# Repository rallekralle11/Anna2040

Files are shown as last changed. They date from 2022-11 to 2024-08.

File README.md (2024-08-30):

# Anna 2040

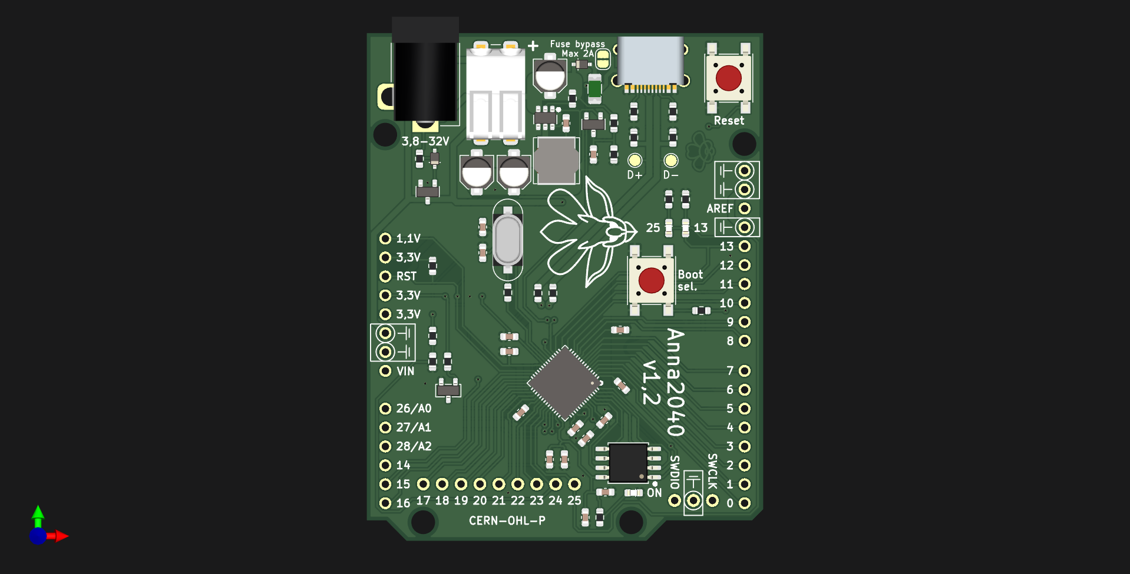
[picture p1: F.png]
board


Similar feature set to the Raspberry pi pico in the classic uno shape.

USB-C

2MB flash memory

all IO pins available

proper analog voltage reference

3,8-32V buck converter with:

lossless reverse polarity protection on the power inputs

data line ESD protection

USB power fuse

LEDs on both pin 13 and 25 as on the uno and pico

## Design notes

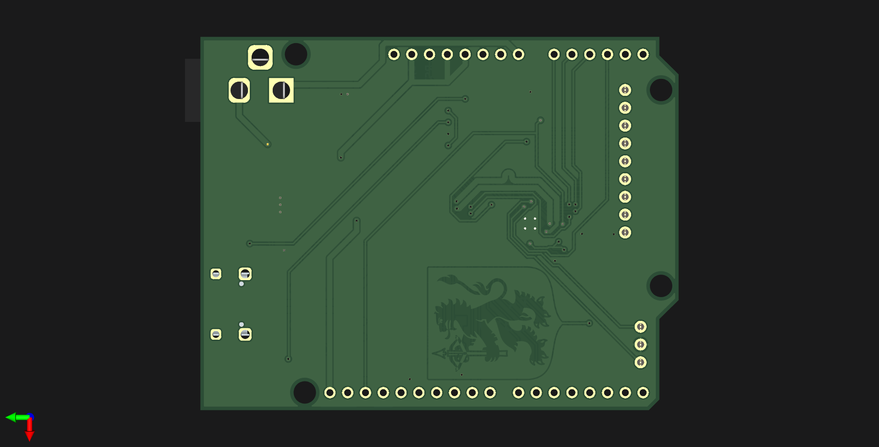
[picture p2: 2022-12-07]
B.png

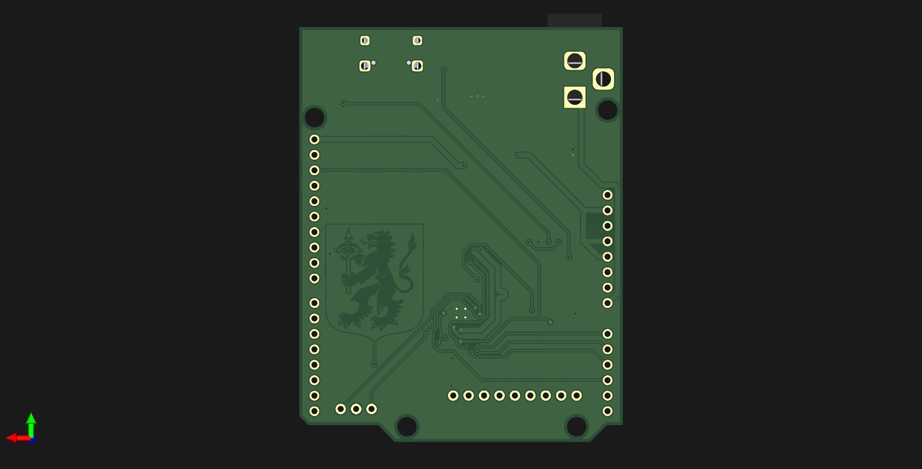
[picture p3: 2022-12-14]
B.jpg

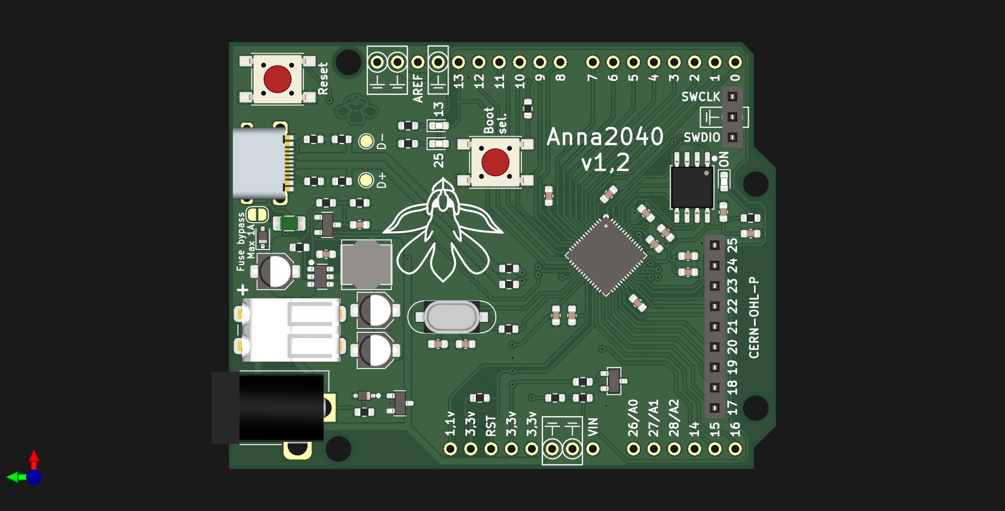
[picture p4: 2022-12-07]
anac_2040.jpg

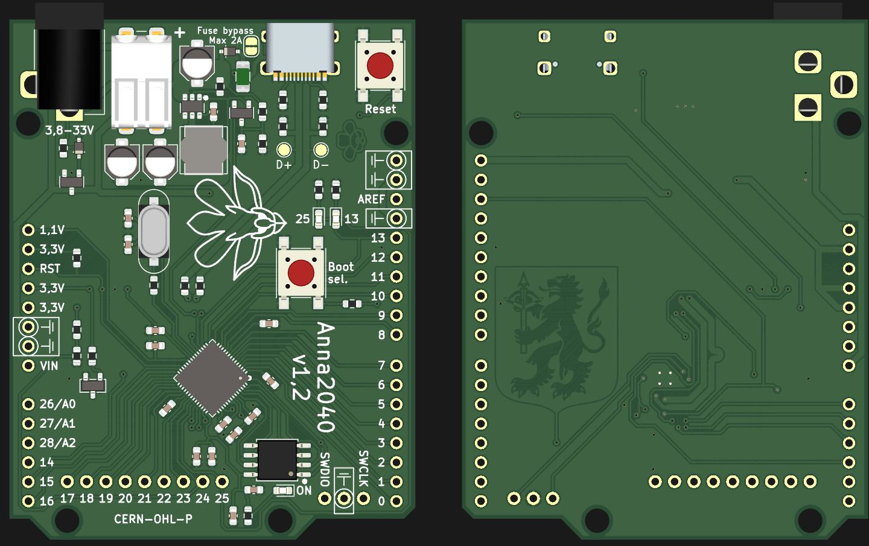
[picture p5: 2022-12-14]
F.jpg

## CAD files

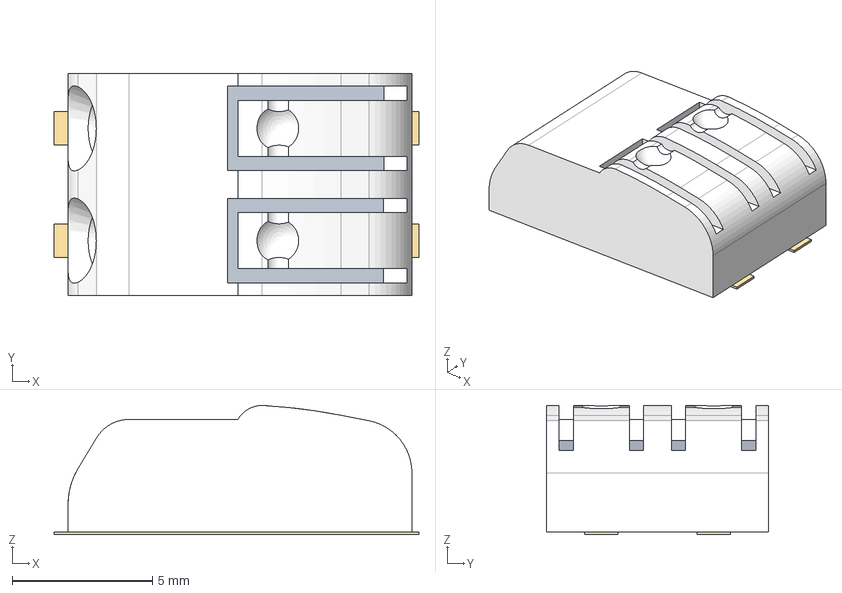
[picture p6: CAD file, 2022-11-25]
wago.stp
13.0 x 7.90 x 4.60 mm

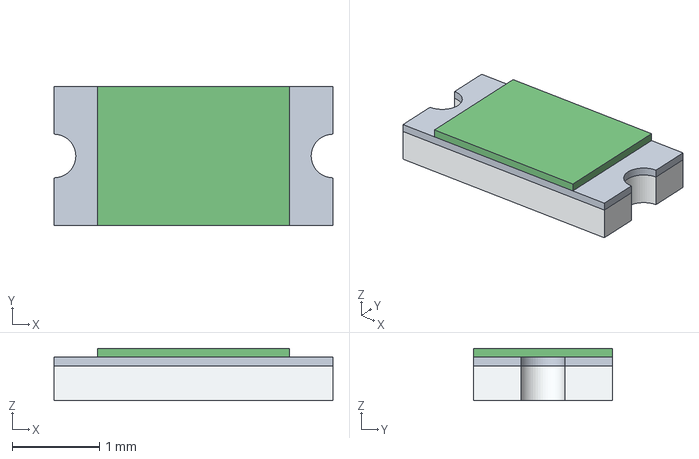
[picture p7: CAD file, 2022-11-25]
fuse.stp
3.20 x 1.60 x 0.6 mm

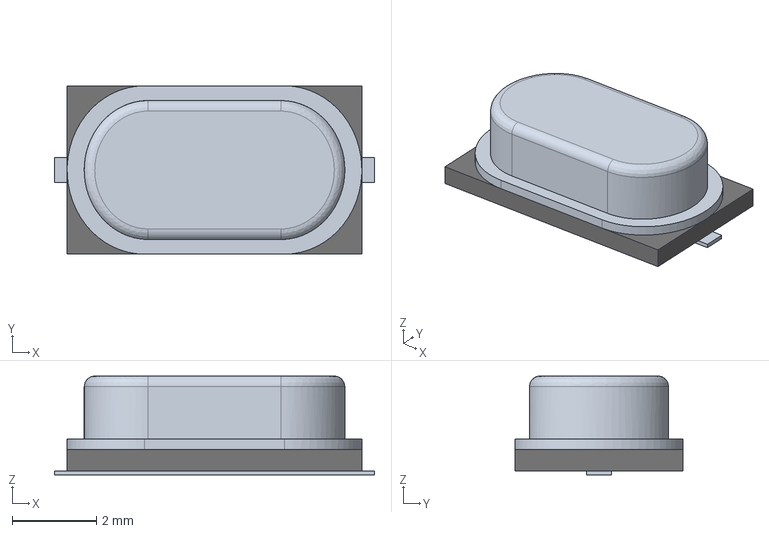
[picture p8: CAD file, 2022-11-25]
crystal.stp
7.60 x 4.00 x 2.35 mm

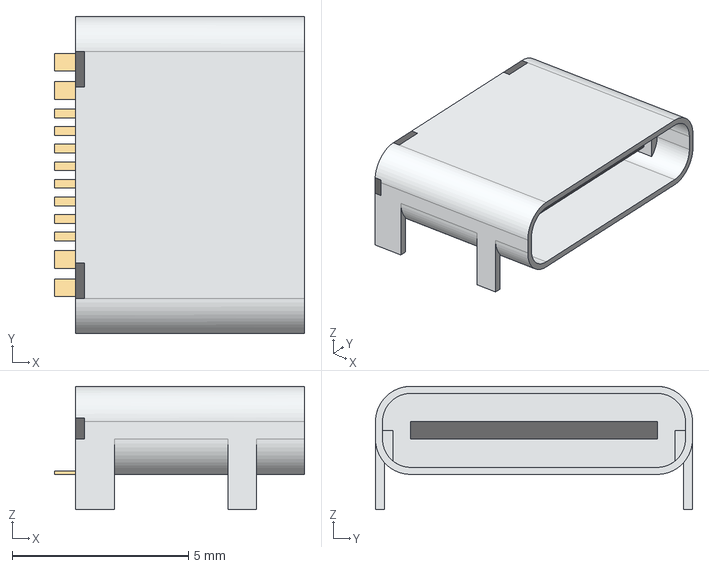
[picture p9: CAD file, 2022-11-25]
USBC.stp
7.10 x 9.00 x 3.50 mm

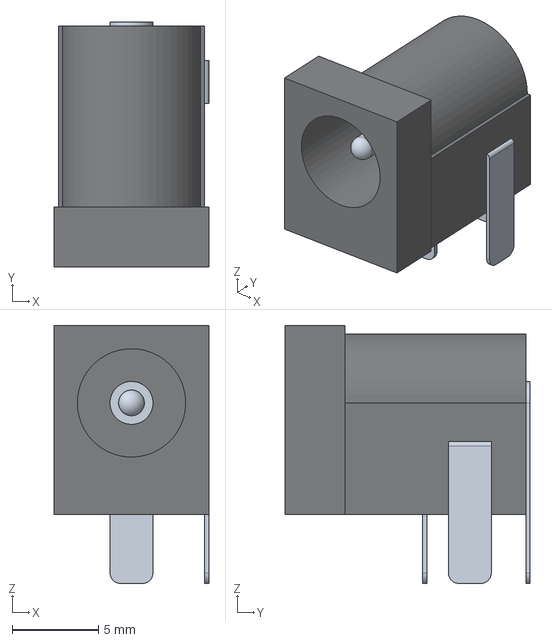
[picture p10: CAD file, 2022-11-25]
barrel_jack.stp
9.00 x 14.3 x 15.0 mm

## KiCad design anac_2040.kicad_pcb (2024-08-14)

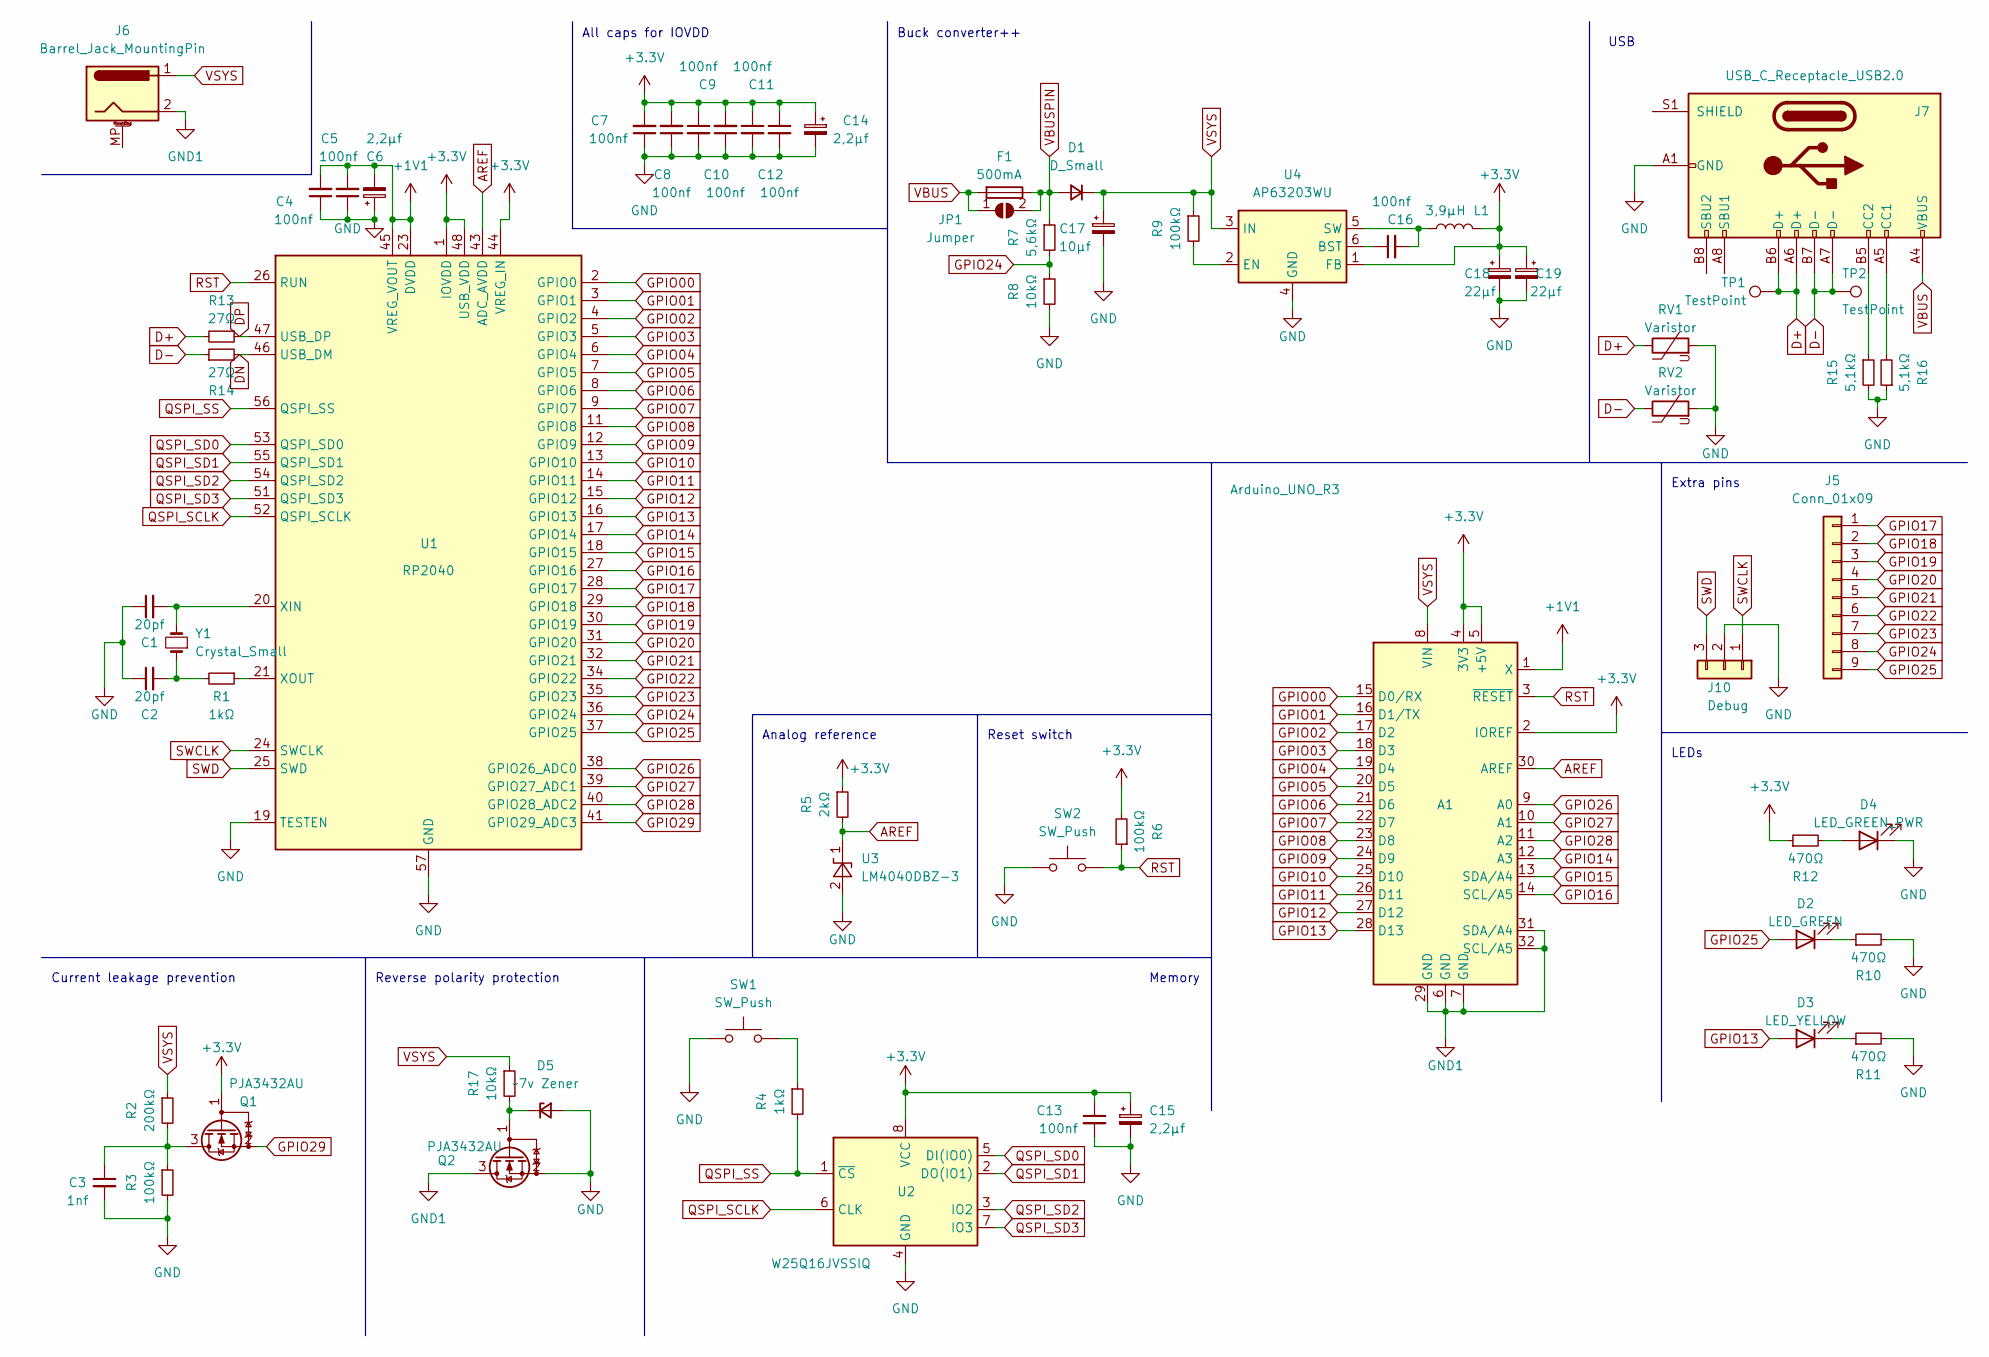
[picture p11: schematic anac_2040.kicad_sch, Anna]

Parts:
A1: Arduino_UNO_R3
C1, C2: 20pf; C_0402_1005Metric
C3: 1nf; C_0402_1005Metric
C4, C5, C7, C8, C9, C10, C11, C12, C13, C16: 100nf; C_0402_1005Metric
C6, C14, C15: 2,2µf; C_0402_1005Metric
C17: 10µf; CP_Elec_4x4.5
C18, C19: 22µf; CP_Elec_4x4.5
D1: D_Small; D_SOD-323
D2: LED_GREEN; LED_0402_1005Metric
D3: LED_YELLOW; LED_0402_1005Metric
D4: LED_GREEN_PWR; LED_0402_1005Metric
D5: ~7v Zener; D_SOD-323
F1: 500mA; Fuse_1206_3216Metric
J5: Conn_01x09; PinSocket_1x09_P2.54mm_Vertical
J6: Barrel_Jack_MountingPin; BarrelJack_Horizontal
J7: USB_C_Receptacle_USB2.0; TYPE-C-31-M-12
J10: Debug; PinSocket_1x03_P2.54mm_Vertical
JP1: Jumper; SolderJumper-2_P1.3mm_Open_RoundedPad1.0x1.5mm
L1: 3,9µH; L_Bourns_SRN6045TA
Q1, Q2: PJA3432AU; SOT-23
R1, R4: 1kΩ; R_0402_1005Metric
R2: 200kΩ; R_0402_1005Metric
R3, R6, R9: 100kΩ; R_0402_1005Metric
R5: 2kΩ; R_0402_1005Metric
R7: 5,6kΩ; R_0402_1005Metric
R8, R17: 10kΩ; R_0402_1005Metric
R10, R11, R12: 470Ω; R_0402_1005Metric
R13, R14: 27Ω; R_0402_1005Metric
R15, R16: 5,1kΩ; R_0402_1005Metric
RV1, RV2: Varistor; R_0402_1005Metric
SW1, SW2: SW_Push; SW_Push_1P1T_NO_6x6mm_H9.5mm
TP1, TP2: TestPoint; TestPoint_Pad_D1.5mm
U1: RP2040; QFN-56-1EP_7x7mm_P0.4mm_EP3.2x3.2mm
U2: W25Q16JVSSIQ; SOIC-8_5.23x5.23mm_P1.27mm
U3: LM4040DBZ-3; SOT-23
U4: AP63203WU; TSOT-23-6
Y1: Crystal_Small; Crystal_SMD_7050-2Pin_7.0x5.0mm

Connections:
+1V1: A1.1 (X), C4.2, C5.2, C6.2, U1.23 (DVDD), U1.45 (VREG_VOUT), U1.50 (DVDD)
+3.3V: A1.2 (IOREF), A1.4 (3V3), A1.5 (+5V), C7.2, C8.2, C9.1, C10.2, C11.1, C12.1, C13.1, C14.1, C15.1, C18.1, C19.1, L1.2, Q1.1 (G), R5.1, R6.2, R12.1, U1.1 (IOVDD), U1.10 (IOVDD), U1.22 (IOVDD), U1.33 (IOVDD), U1.42 (IOVDD), U1.44 (VREG_IN), U1.48 (USB_VDD), U1.49 (IOVDD), U2.8 (VCC), U4.1 (FB)
AREF: A1.30 (AREF), R5.2, U1.43 (ADC_AVDD), U3.1 (K)
D+: J7.A6 (D+), J7.B6 (D+), R13.2, RV1.1, TP1.1
D-: J7.A7 (D-), J7.B7 (D-), R14.1, RV2.1, TP2.1
DN: R14.2, U1.46 (USB_DM)
DP: R13.1, U1.47 (USB_DP)
GND: C1.1, C2.1, C3.2, C4.1, C5.1, C6.1, C7.1, C8.1, C9.2, C10.1, C11.2, C12.2, C13.2, C14.2, C15.2, C17.2, C18.2, C19.2, D4.1 (K), D5.2 (A), J7.A1 (GND), J7.A12 (GND), J7.B1 (GND), J7.B12 (GND), J10.2, Q2.2 (S), R3.2, R8.2, R10.2, R11.2, R15.2, R16.1, RV1.2, RV2.2, SW1.1, SW2.1, U1.19 (TESTEN), U1.57 (GND), U2.4 (GND), U3.2 (A), U4.4 (GND)
GND1: A1.6 (GND), A1.7 (GND), A1.29 (GND), A1.31 (SDA/A4), A1.32 (SCL/A5), J6.2, Q2.3 (D)
GPIO00: A1.15 (D0/RX), U1.2 (GPIO0)
GPIO01: A1.16 (D1/TX), U1.3 (GPIO1)
GPIO02: A1.17 (D2), U1.4 (GPIO2)
GPIO03: A1.18 (D3), U1.5 (GPIO3)
GPIO04: A1.19 (D4), U1.6 (GPIO4)
GPIO05: A1.20 (D5), U1.7 (GPIO5)
GPIO06: A1.21 (D6), U1.8 (GPIO6)
GPIO07: A1.22 (D7), U1.9 (GPIO7)
GPIO08: A1.23 (D8), U1.11 (GPIO8)
GPIO09: A1.24 (D9), U1.12 (GPIO9)
GPIO10: A1.25 (D10), U1.13 (GPIO10)
GPIO11: A1.26 (D11), U1.14 (GPIO11)
GPIO12: A1.27 (D12), U1.15 (GPIO12)
GPIO13: A1.28 (D13), D3.2 (A), U1.16 (GPIO13)
GPIO14: A1.12 (A3), U1.17 (GPIO14)
GPIO15: A1.13 (SDA/A4), U1.18 (GPIO15)
GPIO16: A1.14 (SCL/A5), U1.27 (GPIO16)
GPIO17: J5.1, U1.28 (GPIO17)
GPIO18: J5.2, U1.29 (GPIO18)
GPIO19: J5.3, U1.30 (GPIO19)
GPIO20: J5.4, U1.31 (GPIO20)
GPIO21: J5.5, U1.32 (GPIO21)
GPIO22: J5.6, U1.34 (GPIO22)
GPIO23: J5.7, U1.35 (GPIO23)
GPIO24: J5.8, R7.2, R8.1, U1.36 (GPIO24)
GPIO25: D2.2 (A), J5.9, U1.37 (GPIO25)
GPIO26: A1.9 (A0), U1.38 (GPIO26_ADC0)
GPIO27: A1.10 (A1), U1.39 (GPIO27_ADC1)
GPIO28: A1.11 (A2), U1.40 (GPIO28_ADC2)
GPIO29: Q1.2 (S), U1.41 (GPIO29_ADC3)
unnamed: C2.2, R1.2, Y1.1
unnamed: D2.1 (K), R10.1
unnamed: D3.1 (K), R11.1
unnamed: D4.2 (A), R12.2
unnamed: D5.1 (K), Q2.1 (G), R17.2
unnamed: J7.A5 (CC1), R16.2
unnamed: J7.B5 (CC2), R15.1
unnamed: C3.1, Q1.3 (D), R2.2, R3.1
unnamed: R4.1, SW1.2
unnamed: C1.2, U1.20 (XIN), Y1.2
unnamed: R1.1, U1.21 (XOUT)
unnamed: C16.1, U4.6 (BST)
unnamed: R9.2, U4.2 (EN)
unnamed: C16.2, L1.1, U4.5 (SW)
QSPI_SCLK: U1.52 (QSPI_SCLK), U2.6 (CLK)
QSPI_SD0: U1.53 (QSPI_SD0), U2.5 (DI(IO0))
QSPI_SD1: U1.55 (QSPI_SD1), U2.2 (DO(IO1))
QSPI_SD2: U1.54 (QSPI_SD2), U2.3 (IO2)
QSPI_SD3: U1.51 (QSPI_SD3), U2.7 (IO3)
QSPI_SS: R4.2, U1.56 (QSPI_SS), U2.1 (~CS)
RST: A1.3 (~RESET), R6.1, SW2.2, U1.26 (RUN)
SWCLK: J10.1, U1.24 (SWCLK)
SWD: J10.3, U1.25 (SWD)
VBUS: F1.2, J7.A4 (VBUS), J7.A9 (VBUS), J7.B4 (VBUS), J7.B9 (VBUS), JP1.1 (A)
VBUSPIN: D1.2 (A), F1.1, JP1.2 (B), R7.1
VSYS: A1.8 (VIN), C17.1, D1.1 (K), J6.1, R2.1, R9.1, R17.1, U4.3 (IN)

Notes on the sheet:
Memory
Analog reference
Extra pins
Current leakage prevention
All caps for IOVDD
Reverse polarity protection
LEDs
Reset switch
Buck converter++
USB

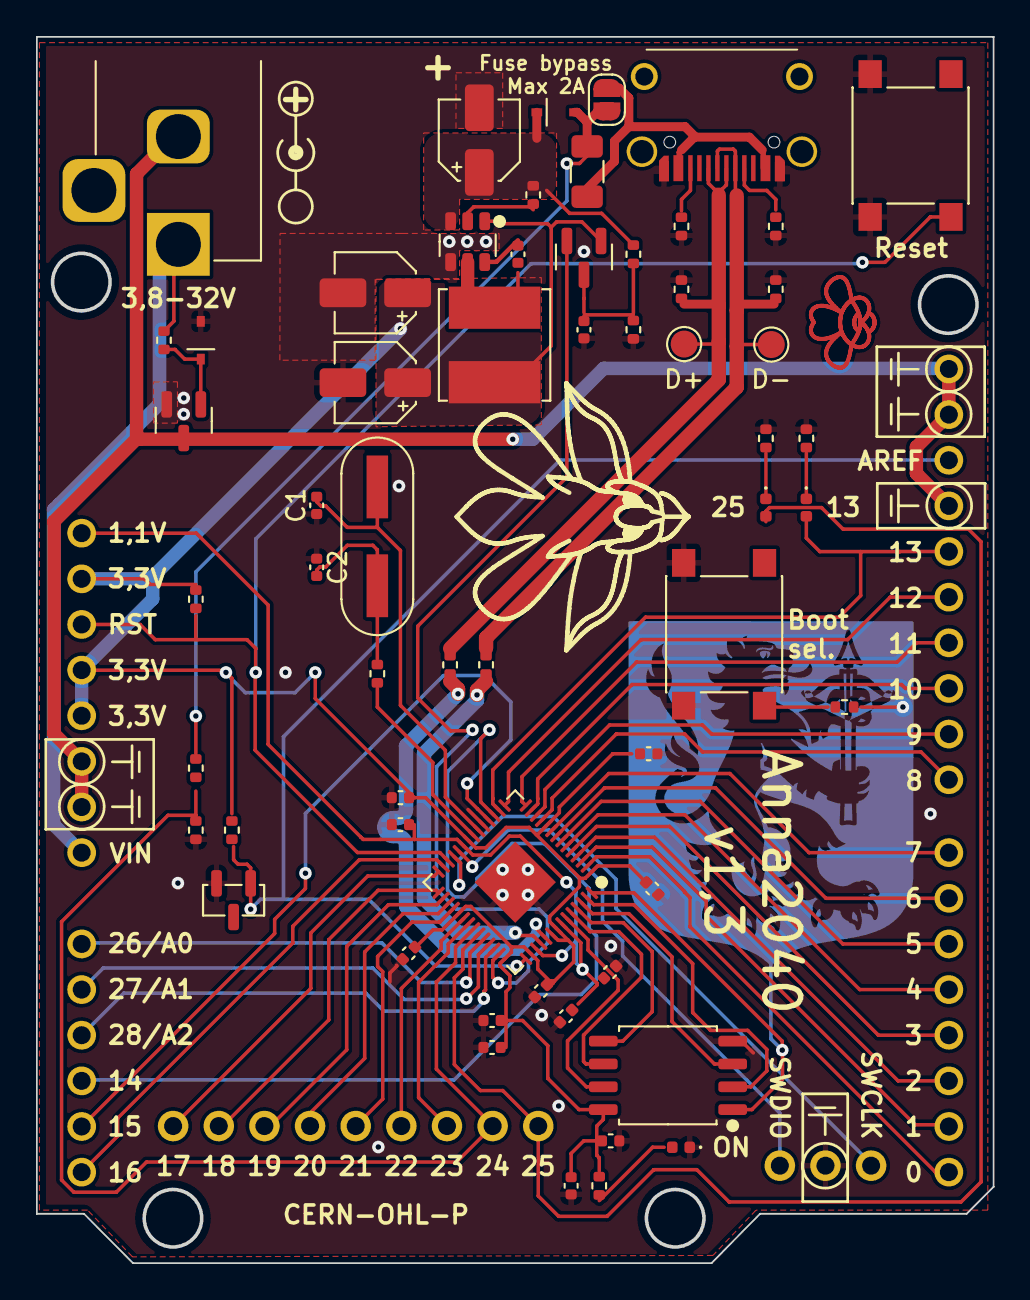
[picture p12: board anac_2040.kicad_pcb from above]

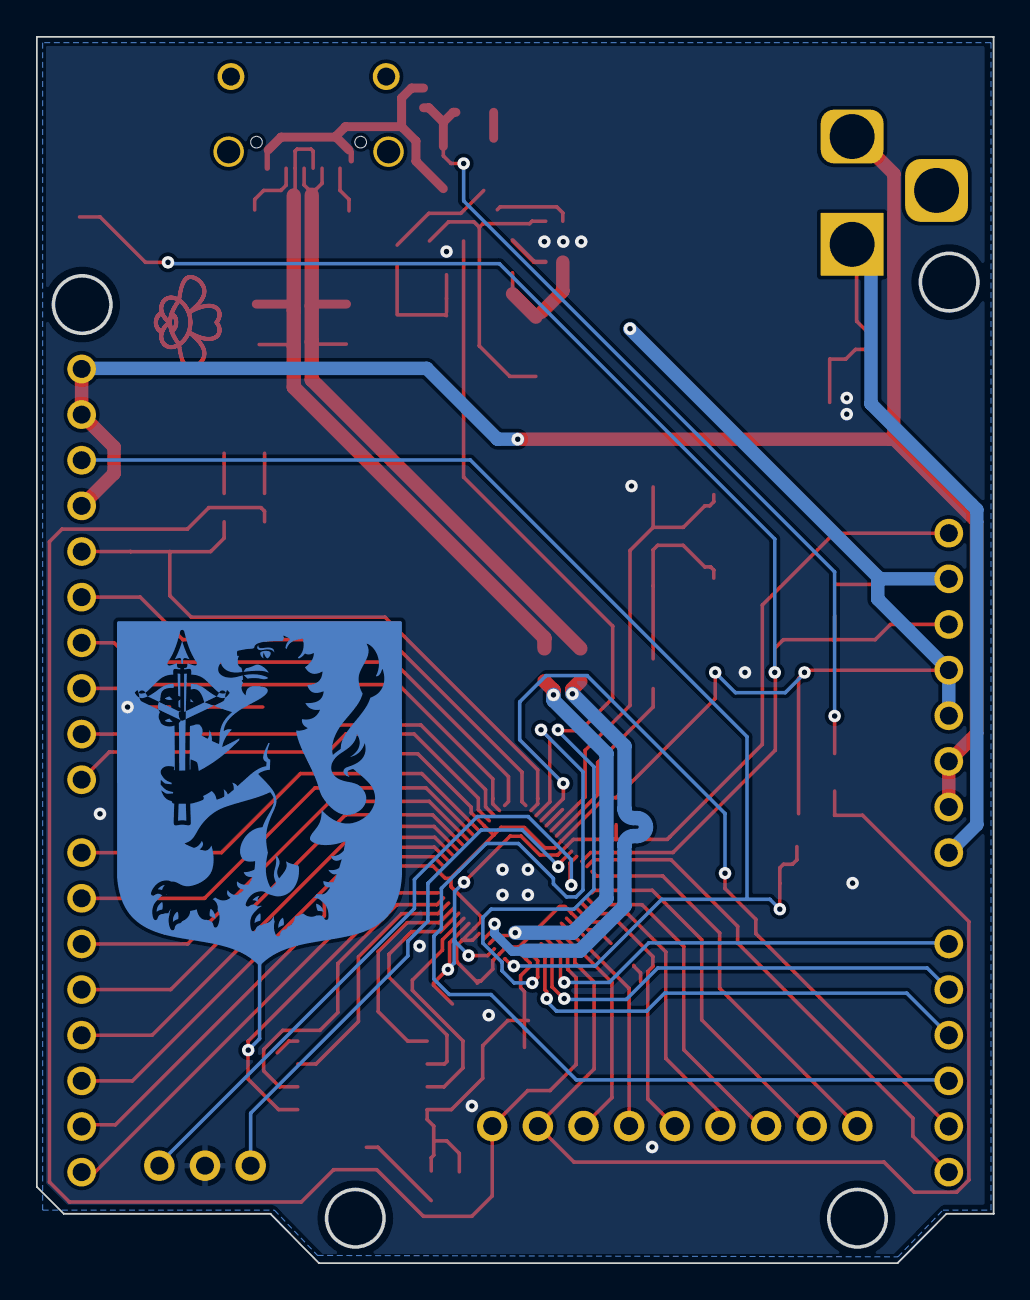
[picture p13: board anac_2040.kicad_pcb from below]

Board: 2 copper layers, 53.2 x 68.2 mm, 62 parts (2 on the bottom side), 65 nets.

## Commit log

2022-11-25 small update
    [anac_2040.kicad_pcb, anac_2040.kicad_sch, wago.stp]
2022-11-25 added gerbers
    [anac_2040.kicad_pcb]
2022-11-25 fixed things
    [anac_2040.kicad_pcb]
2022-11-25 Update wago 4mm.123dx
2022-12-07 few fixes
    [anac_2040.kicad_pcb, anac_2040.kicad_sch]
2022-12-14 i forget
    [anac_2040.kicad_pcb, anac_2040.kicad_sch]
2022-12-17 new BOM and readme update
2022-12-17 small design change
    [anac_2040-B_Cu.gbr, anac_2040-B_Mask.gbr, anac_2040-B_Paste.gbr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]

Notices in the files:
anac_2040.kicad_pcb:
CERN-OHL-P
